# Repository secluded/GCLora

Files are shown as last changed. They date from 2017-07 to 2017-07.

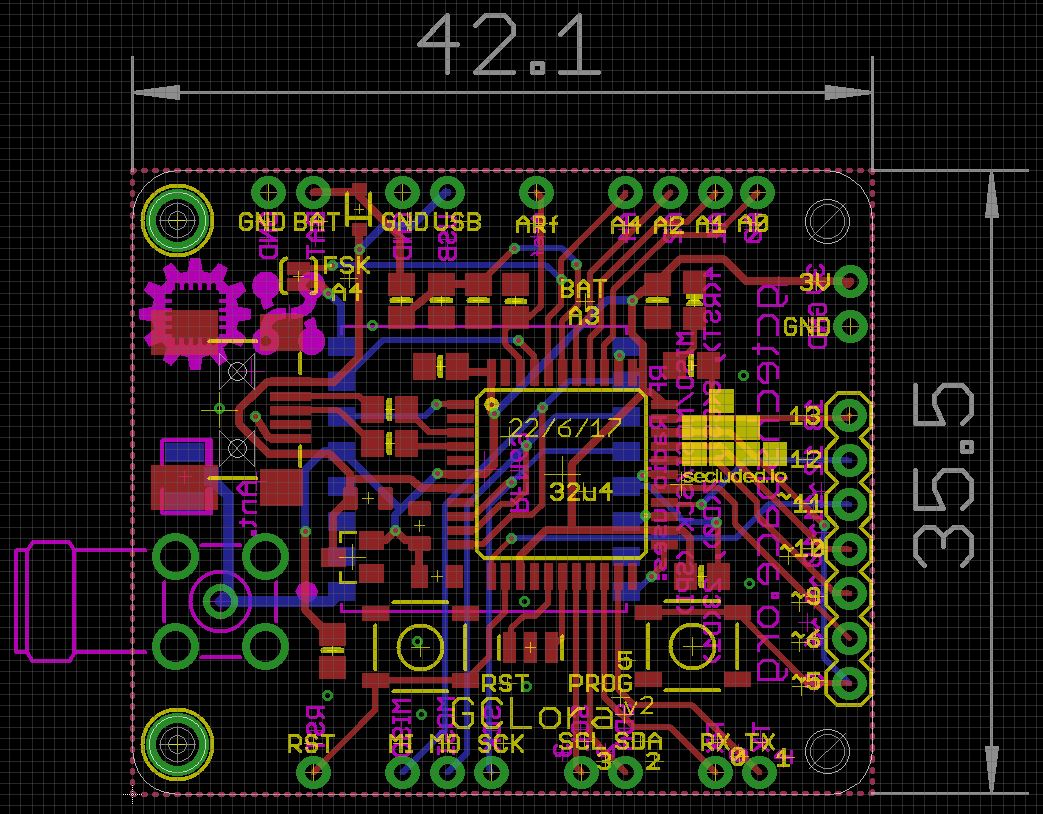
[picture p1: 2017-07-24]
GCLoraPCB.JPG

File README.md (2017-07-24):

# GCLora
An Arduino with a RFM95 Radio module capable of LoRa transmittions

Select "Lillypad Arduino USB" as the board type in the Arduino IDE
The GCLora board should automatically reconnect on another COM port for uploading code, 
then return to the orignal port on completion.
If this fails, double pressing the reset button will put it into upload mode, the led will pulse.

Pins RF Radio uses:<br>
MISO/MOSI/SCK (SPI)<br>
Version 1<br>
4(RST), 8(CS), A0(D0), 23(D1), A4(D2) is connectable by closing the jumper.<br>
Version 2 - enable use of Radiohead Library for non LoRaWan applications<br>
4(RST), 8(CS), 7(D0), 23(D1), A4(D2) is connectable by closing the jumper.<br>

For Australian use, please clone our Arduino/LMIC repo as it has the frequencies mapped correctly.

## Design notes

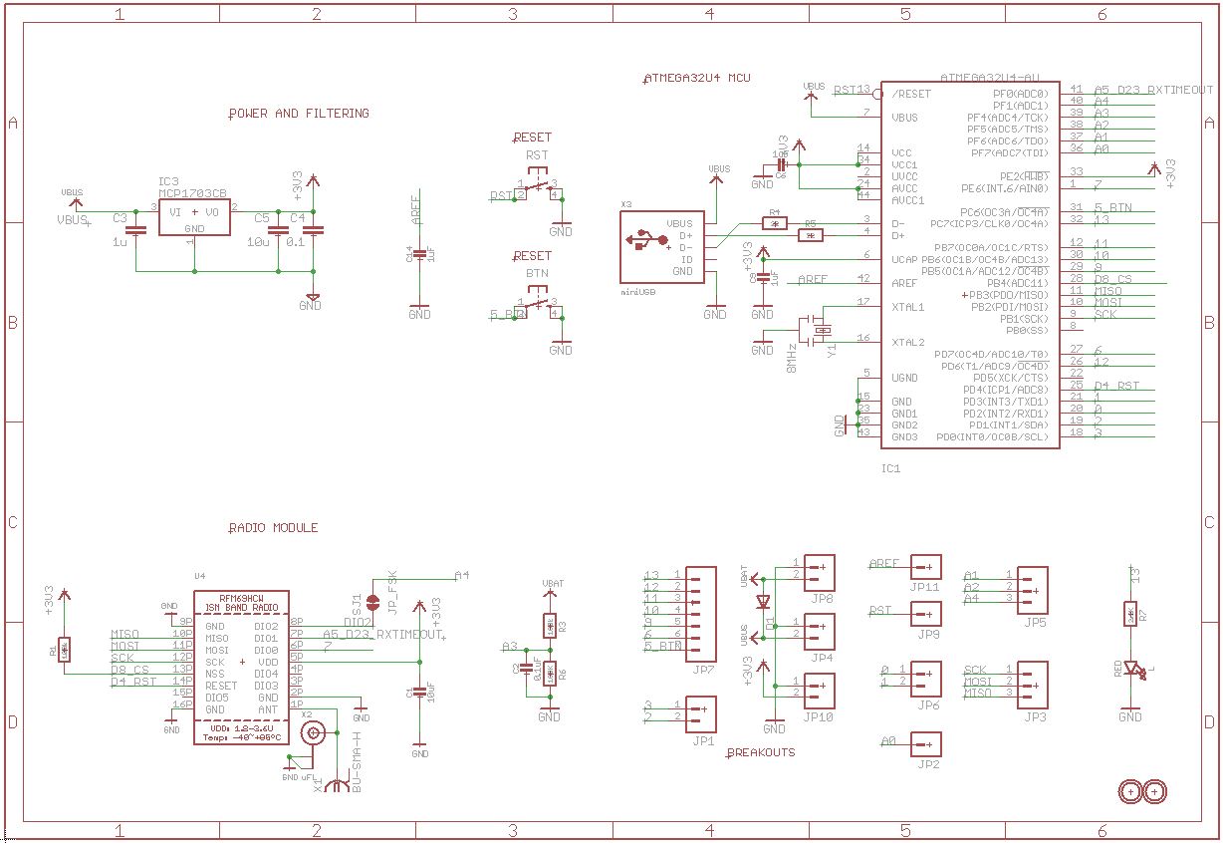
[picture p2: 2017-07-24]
GCLoraSCH.JPG

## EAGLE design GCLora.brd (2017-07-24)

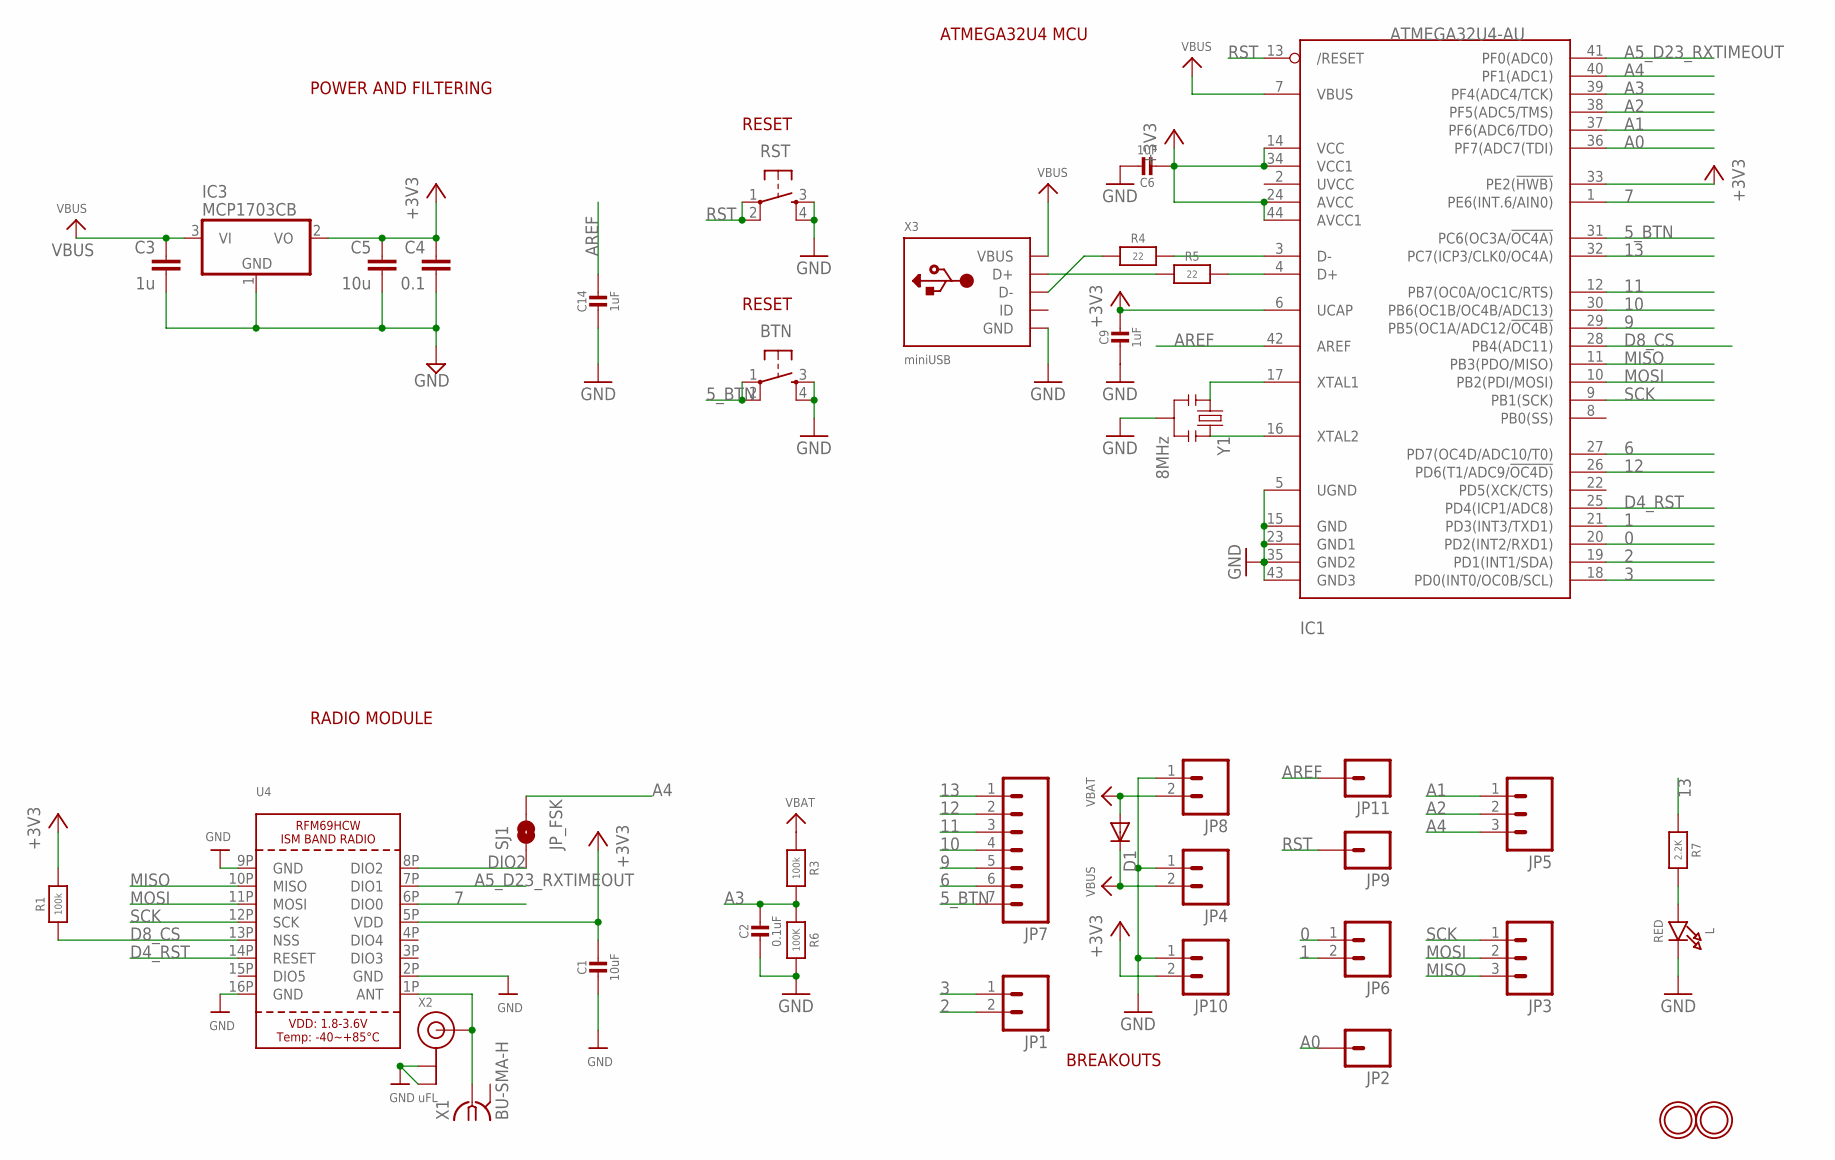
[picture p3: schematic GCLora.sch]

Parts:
BTN: TAC_SWITCHSMD; TACTILE_SWITCH_SMD
C1: 10uF; 0805-NO
C2: 0.1uF; 0805-NO
C3: 1u; 0805
C4: 0.1; 0805
C5: 10u; 0805-CAP
C6, C9, C14: 1uF; 0805-NO
D1: DIODESOD; SOD-323
IC1: ATMEGA32U4-AU; TQFP44
IC3: MCP1703CB; SOT23
JP1, JP4, JP6, JP8, JP10: M021X02_NO_SILK; 1X02_NO_SILK
JP2, JP9, JP11: M01PTH_NO_SILK_YES_STOP; 1X01_NO_SILK
JP3, JP5: M031X03_NO_SILK; 1X03_NO_SILK
JP7: M07; 1X07
L: RED; CHIPLED_0805_NOOUTLINE
R1, R3: 100k; 0805-NO
R4, R5: 22; 0805-NO
R6: 100K; 0805-NO
R7: 2.2K; 0805-NO
RST: TAC_SWITCHSMD; TACTILE_SWITCH_SMD
SJ1: JP_FSK; SPARKFUN-PASSIVES_SJ_2S-NO
U4: RFM69HCW_SMT; RFMHCW_SMT
U$31, U$32: MOUNTINGHOLE2.5; MOUNTINGHOLE_2.5_PLATED
X1: BU-SMA-H
X2: uFL; U.FL
X3: miniUSB; USB-MINIB_LARGER
Y1: 8MHz; RESONATOR-SMD

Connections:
0: IC1.20 (PD2(INT2/RXD1)), JP6.1
1: IC1.21 (PD3(INT3/TXD1)), JP6.2
2: IC1.19 (PD1(INT1/SDA)), JP1.2
3: IC1.18 (PD0(INT0/OC0B/SCL)), JP1.1
5_BTN: BTN.1, BTN.2, IC1.31 (PC6(OC3A/!OC4A)), JP7.7
6: IC1.27 (PD7(OC4D/ADC10/T0)), JP7.6
7: IC1.1 (PE6(INT.6/AIN0)), U4.6P (DIO0)
9: IC1.29 (PB5(OC1A/ADC12/!OC4B)), JP7.5
10: IC1.30 (PB6(OC1B/OC4B/ADC13)), JP7.4
11: IC1.12 (PB7(OC0A/OC1C/RTS)), JP7.3
12: IC1.26 (PD6(T1/ADC9/!OC4D)), JP7.2
13: IC1.32 (PC7(ICP3/CLK0/OC4A)), JP7.1, R7.1
+3V3: C1.1, C4.1, C5.1, C6.2, C9.1, IC1.6 (UCAP), IC1.14 (VCC), IC1.24 (AVCC), IC1.33 (PE2(!HWB)), IC1.34 (VCC1), IC1.44 (AVCC1), IC3.2 (VO), JP10.2, R1.2, U4.5P (VDD)
A0: IC1.36 (PF7(ADC7(TDI)), JP2.1
A1: IC1.37 (PF6(ADC6/TDO)), JP5.1
A2: IC1.38 (PF5(ADC5/TMS)), JP5.2
A3: C2.1, IC1.39 (PF4(ADC4/TCK)), R3.2, R6.1
A4: IC1.40 (PF1(ADC1)), JP5.3, SJ1.2
A5_D23_RXTIMEOUT: IC1.41 (PF0(ADC0)), U4.7P (DIO1)
ANT: U4.1P (ANT), X1.1, X2.3 (SIGNAL)
AREF: C14.1, IC1.42 (AREF), JP11.1
D4_RST: IC1.25 (PD4(ICP1/ADC8)), U4.14P (RESET)
D8_CS: IC1.28 (PB4(ADC11)), R1.1, U4.13P (NSS)
D+: IC1.4 (D+), R5.2
D-: IC1.3 (D-), R4.2
DIO2: SJ1.1, U4.8P (DIO2)
GND: BTN.3, BTN.4, C1.2, C2.2, C3.2, C4.2, C5.2, C6.1, C9.2, C14.2, IC1.5 (UGND), IC1.15 (GND), IC1.23 (GND1), IC1.35 (GND2), IC1.43 (GND3), IC3.1 (GND), JP4.1, JP8.1, JP10.1, L.C, R6.2, RST.3, RST.4, U4.2P (GND), U4.9P (GND), U4.16P (GND), X1.2 (GND), X1.3 (GND), X1.4 (GND), X1.5 (GND), X2.1 (GND), X2.2 (GND), X3.GND, X3.GND1 (GND), X3.GND2 (GND), X3.GND3 (GND), X3.GND4 (GND), Y1.2
MISO: IC1.11 (PB3(PDO/MISO)), JP3.3, U4.10P (MISO)
MOSI: IC1.10 (PB2(PDI/MOSI)), JP3.2, U4.11P (MOSI)
unnamed: L.A, R7.2
unnamed: IC1.16 (XTAL2), Y1.3
unnamed: IC1.17 (XTAL1), Y1.1
unnamed: R5.1, X3.D+
unnamed: R4.1, X3.D-
RST: IC1.13 (/RESET), JP9.1, RST.1, RST.2
SCK: IC1.9 (PB1(SCK)), JP3.1, U4.12P (SCK)
VBAT: D1.2 (A), JP8.2, R3.1
VBUS: C3.1, D1.1 (C), IC1.7 (VBUS), IC3.3 (VI), JP4.2, X3.VBUS

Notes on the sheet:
POWER AND FILTERING
RESET
ATMEGA32U4 MCU
BREAKOUTS
RADIO MODULE

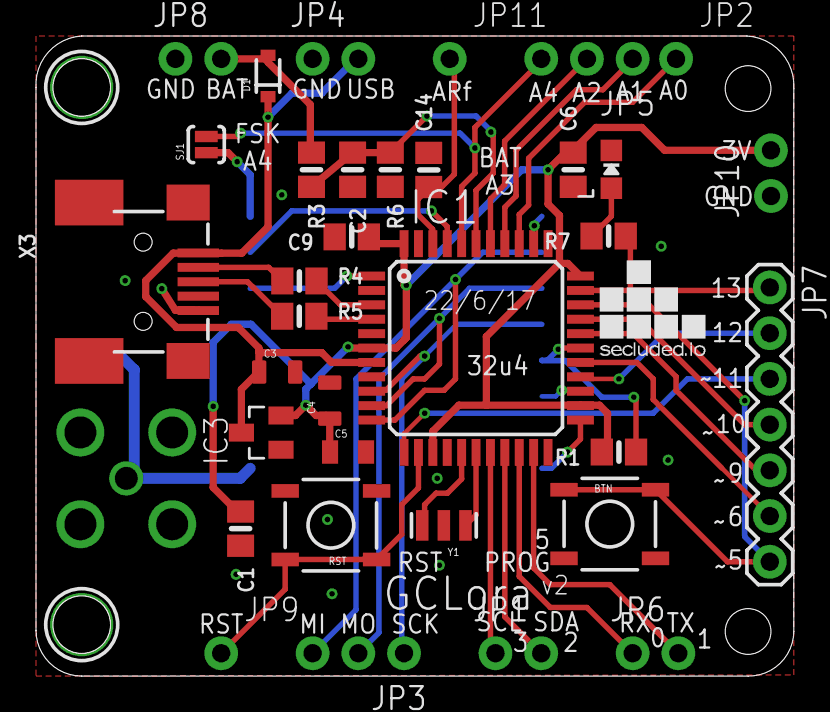
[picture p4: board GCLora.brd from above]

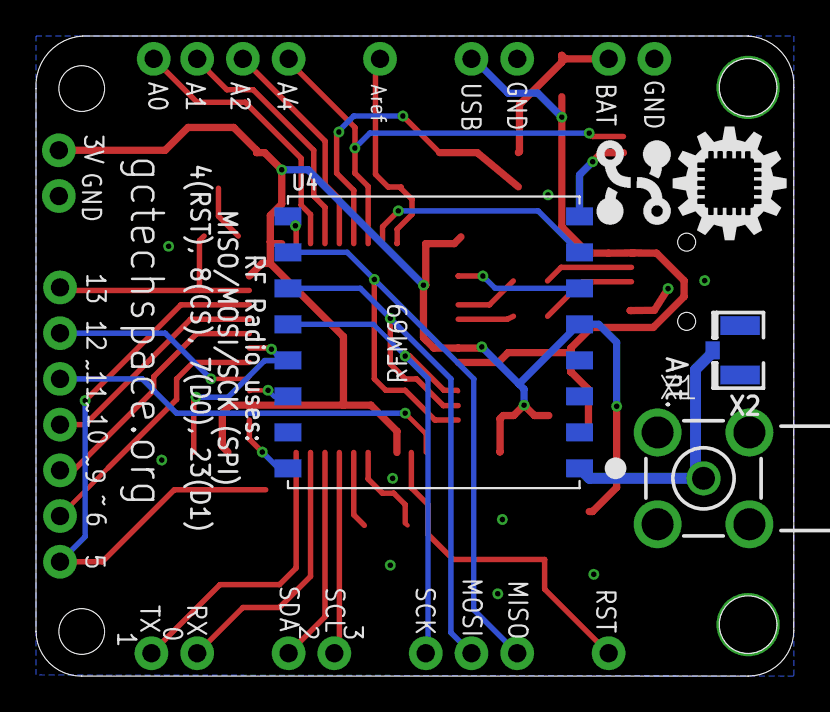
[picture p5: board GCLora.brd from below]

Board: 2 copper layers, 42.1 x 35.6 mm, 42 parts (5 on the bottom side), 38 nets.

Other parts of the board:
U$6: ESPDUINO_LOGO_5MM
U$7: SECLUDED_5MM
U$15: ID_LOGO_X0.25

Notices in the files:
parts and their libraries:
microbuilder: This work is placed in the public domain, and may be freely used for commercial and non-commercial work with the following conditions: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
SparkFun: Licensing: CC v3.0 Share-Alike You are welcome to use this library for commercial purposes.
